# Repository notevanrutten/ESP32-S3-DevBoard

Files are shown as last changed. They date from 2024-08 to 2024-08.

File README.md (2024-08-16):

# ESP32-S3-DevBoard

A custom-built development board using the ESP32-S3 chip

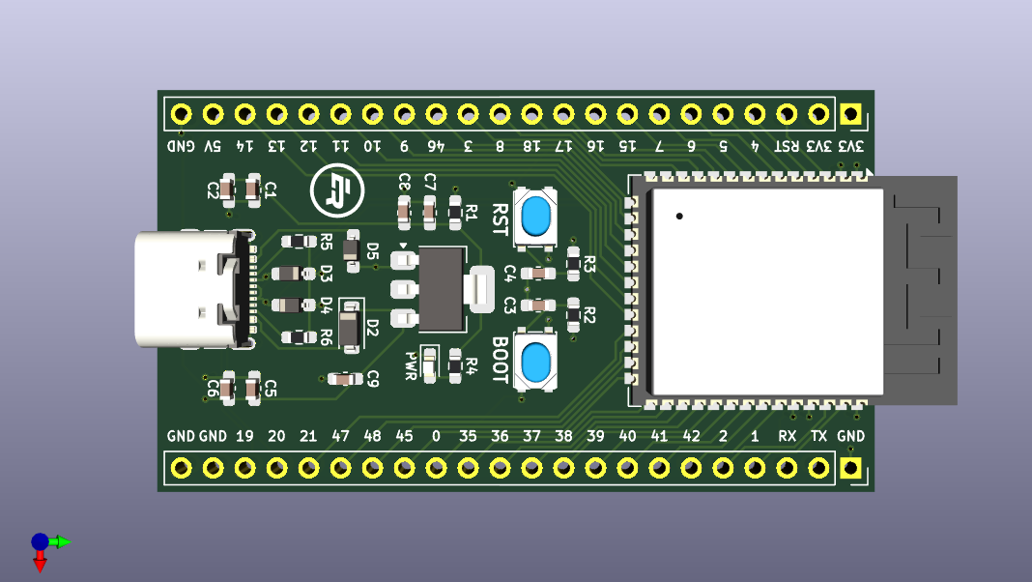
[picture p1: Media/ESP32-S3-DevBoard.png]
ESP32-S3 DevBoard


## PlatformIO Setup

**NOTE:** This process only needs to be performed once for each development board

1. Download the Zadig driver installation program here: https://zadig.akeo.ie
2. Open Zadig, then click `Options -> List All Devices`
3. Select `USB JTAG/serial debug unit (Interface 0)` and change the driver to **USB Serial (CDC)**
4. Click "Upgrade/Downgrade Driver" (please note, this process may take a few minutes)
5. Select `USB JTAG/serial debug unit (Interface 2)` and change the driver to **libusbK**
6. Click "Upgrade/Downgrade Driver" (please note, this process may take a few minutes)
7. In PlatformIO, configure the platformio.ini file as follows:

   ```ini
    [env:esp32-s3-devboard]

    platform = https://github.com/platformio/platform-espressif32.git
    board = esp32-s3-devkitc-1
    framework = arduino

    upload_speed = 2000000
    monitor_speed = 115200

    debug_tool = esp-builtin
    debug_init_break = break setup
    build_type = debug

    ; enables CDC mode (activates USB-to-Serial)
    build_flags = -DARDUINO_USB_CDC_ON_BOOT=1
   ```

## USB Interface Options

### UART Uploading / Monitoring (Standard)

1. Click the PlatformIO icon on the Activity Bar (left)
2. Navigate to `PROJECT TASKS > esp32-s3-devboard > General > Upload and Monitor` (top left)
3. The firmware will be uploaded automatically and the serial output will be displayed in the terminal

### JTAG Debugging + VCOM Monitoring (Advanced)

1. Click the PlatformIO icon on the Activity Bar (left)
2. Navigate to `QUICK ACCESS > Debug > Start Debugging` (bottom left), or press `F5`
3. The firmware will be uploaded automatically and the debug toolbar will appear (top middle)
4. Use the debug toolbar to Pause/Unpause, Restart, or Stop the program (also has code stepping)
5. To view the serial output while code is unpaused, click `PlatformIO: Serial Monitor` on the Status Bar (bottom)

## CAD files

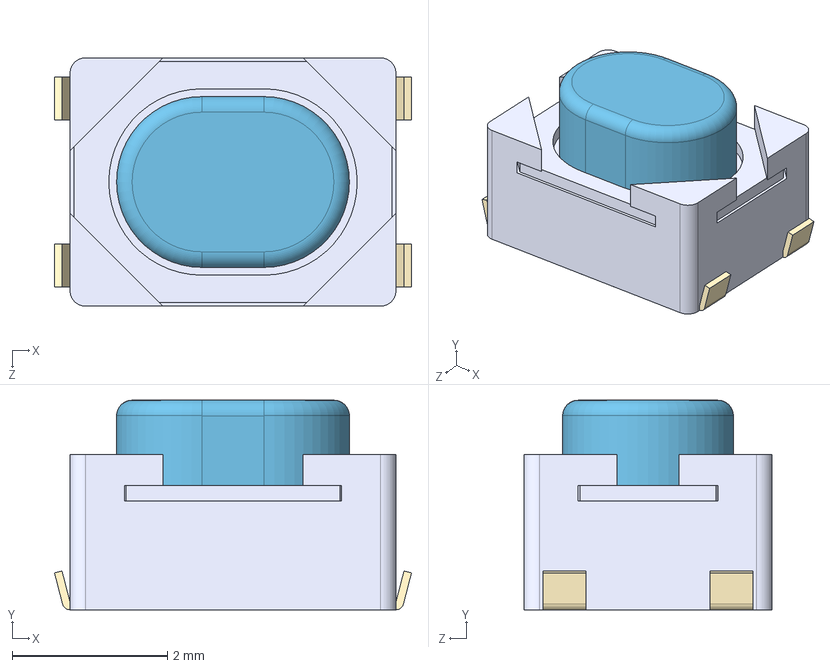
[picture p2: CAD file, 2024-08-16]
Custom/PTS810.STEP
4.60 x 2.70 x 3.20 mm

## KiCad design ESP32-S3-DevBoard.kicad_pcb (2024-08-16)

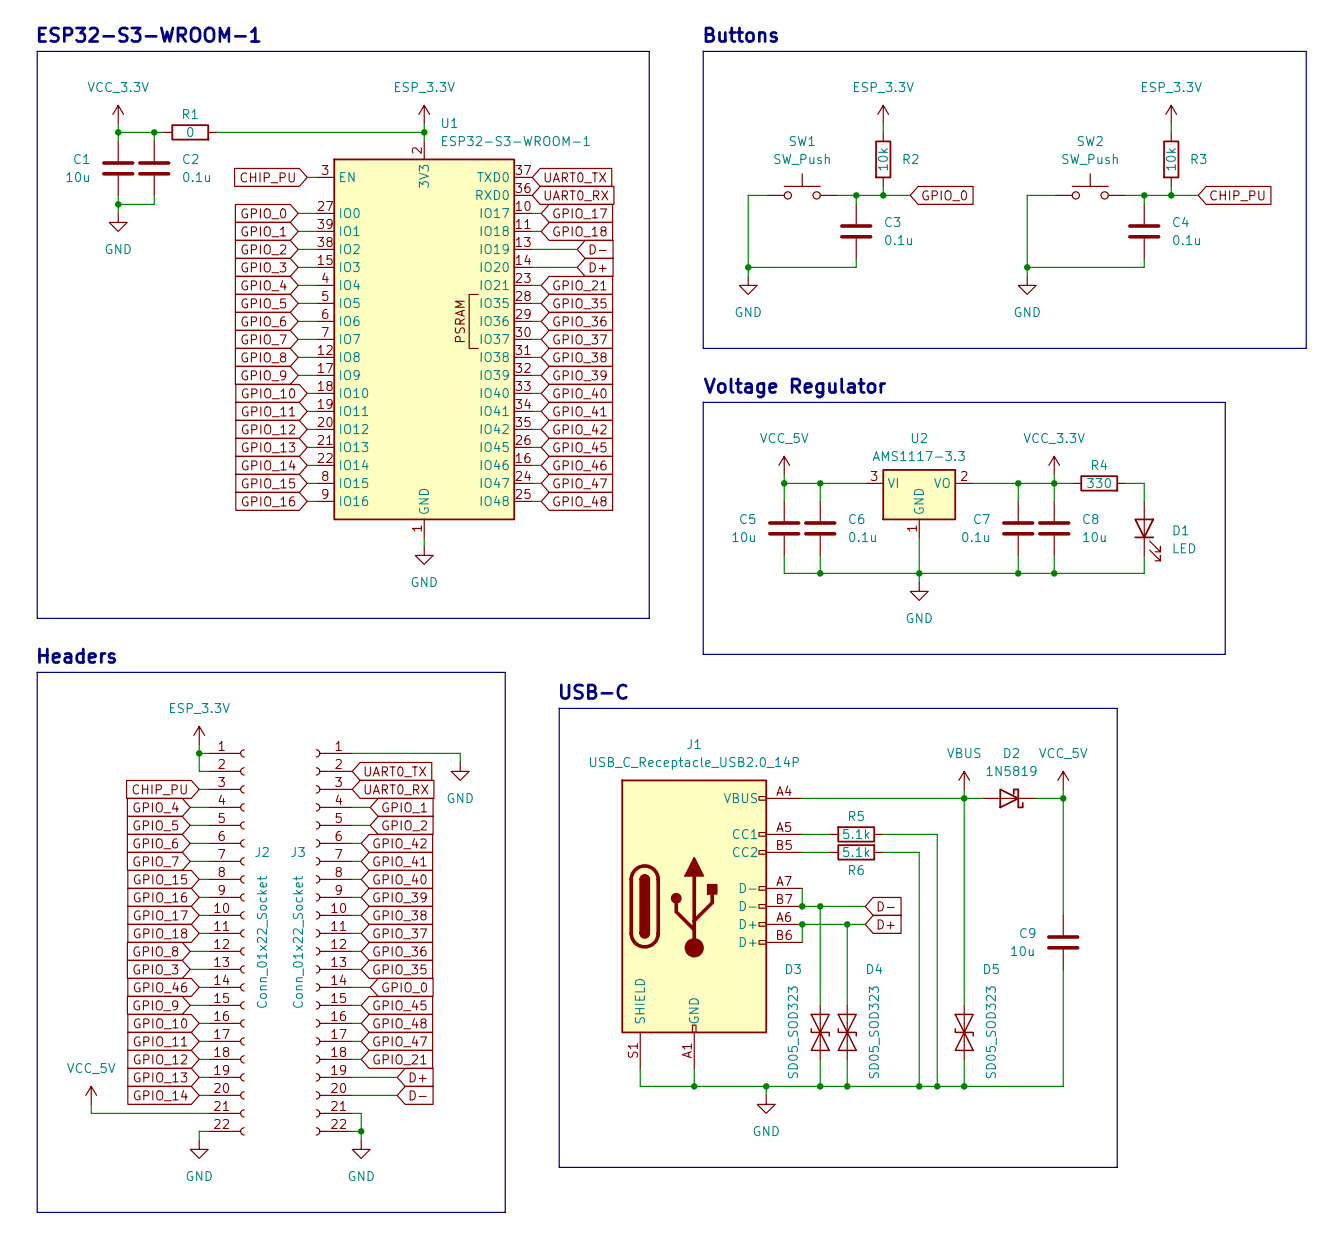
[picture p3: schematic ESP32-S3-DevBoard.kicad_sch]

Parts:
C1, C5, C8, C9: 10u; C_0603_1608Metric_Pad1.08x0.95mm_HandSolder
C2, C3, C4, C6, C7: 0.1u; C_0603_1608Metric_Pad1.08x0.95mm_HandSolder
D1: LED; LED_0603_1608Metric_Pad1.05x0.95mm_HandSolder
D2: 1N5819; D_SOD-123
D3, D4, D5: SD05_SOD323; D_SOD-323_HandSoldering
J1: USB_C_Receptacle_USB2.0_14P; USB_C_Receptacle_GCT_USB4105-xx-A_16P_TopMnt_Horizontal
J2, J3: Conn_01x22_Socket; PinSocket_1x22_P2.54mm_Vertical
R1: 0; R_0603_1608Metric_Pad0.98x0.95mm_HandSolder
R2, R3: 10k; R_0603_1608Metric_Pad0.98x0.95mm_HandSolder
R4: 330; R_0603_1608Metric_Pad0.98x0.95mm_HandSolder
R5, R6: 5.1k; R_0603_1608Metric_Pad0.98x0.95mm_HandSolder
SW1, SW2: SW_Push; SW_SPST_PTS810
U1: ESP32-S3-WROOM-1
U2: AMS1117-3.3; SOT-223-3_TabPin2

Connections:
CHIP_PU: C4.1, J2.3, R3.2, SW2.2, U1.3 (EN)
D+: D4.1 (A1), J1.A6 (D+), J1.B6 (D+), J3.19, U1.14 (IO20)
D-: D3.2 (A2), J1.A7 (D-), J1.B7 (D-), J3.20, U1.13 (IO19)
ESP_3.3V: J2.1, J2.2, R1.2, R2.1, R3.1, U1.2 (3V3)
GND: C1.2, C2.2, C3.2, C4.2, C5.2, C6.2, C7.2, C8.2, C9.2, D1.1 (K), D3.1 (A1), D4.2 (A2), D5.1 (A1), J1.A1 (GND), J1.A12 (GND), J1.B1 (GND), J1.B12 (GND), J1.S1 (SHIELD), J2.22, J3.1, J3.21, J3.22, R5.1, R6.2, SW1.1, SW2.1, U1.1 (GND), U1.40 (GND), U1.41 (GND), U2.1 (GND)
GPIO_0: C3.1, J3.14, R2.2, SW1.2, U1.27 (IO0)
GPIO_1: J3.4, U1.39 (IO1)
GPIO_2: J3.5, U1.38 (IO2)
GPIO_3: J2.13, U1.15 (IO3)
GPIO_4: J2.4, U1.4 (IO4)
GPIO_5: J2.5, U1.5 (IO5)
GPIO_6: J2.6, U1.6 (IO6)
GPIO_7: J2.7, U1.7 (IO7)
GPIO_8: J2.12, U1.12 (IO8)
GPIO_9: J2.15, U1.17 (IO9)
GPIO_10: J2.16, U1.18 (IO10)
GPIO_11: J2.17, U1.19 (IO11)
GPIO_12: J2.18, U1.20 (IO12)
GPIO_13: J2.19, U1.21 (IO13)
GPIO_14: J2.20, U1.22 (IO14)
GPIO_15: J2.8, U1.8 (IO15)
GPIO_16: J2.9, U1.9 (IO16)
GPIO_17: J2.10, U1.10 (IO17)
GPIO_18: J2.11, U1.11 (IO18)
GPIO_21: J3.18, U1.23 (IO21)
GPIO_35: J3.13, U1.28 (IO35)
GPIO_36: J3.12, U1.29 (IO36)
GPIO_37: J3.11, U1.30 (IO37)
GPIO_38: J3.10, U1.31 (IO38)
GPIO_39: J3.9, U1.32 (IO39)
GPIO_40: J3.8, U1.33 (IO40)
GPIO_41: J3.7, U1.34 (IO41)
GPIO_42: J3.6, U1.35 (IO42)
GPIO_45: J3.15, U1.26 (IO45)
GPIO_46: J2.14, U1.16 (IO46)
GPIO_47: J3.17, U1.24 (IO47)
GPIO_48: J3.16, U1.25 (IO48)
unnamed: D1.2 (A), R4.2
unnamed: J1.A5 (CC1), R5.2
unnamed: J1.B5 (CC2), R6.1
UART0_RX: J3.3, U1.36 (RXD0)
UART0_TX: J3.2, U1.37 (TXD0)
VBUS: D2.2 (A), D5.2 (A2), J1.A4 (VBUS), J1.A9 (VBUS), J1.B4 (VBUS), J1.B9 (VBUS)
VCC_3.3V: C1.1, C2.1, C7.1, C8.1, R1.1, R4.1, U2.2 (VO)
VCC_5V: C5.1, C6.1, C9.1, D2.1 (K), J2.21, U2.3 (VI)

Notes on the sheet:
USB-C
Buttons
Headers
ESP32-S3-WROOM-1
Voltage Regulator

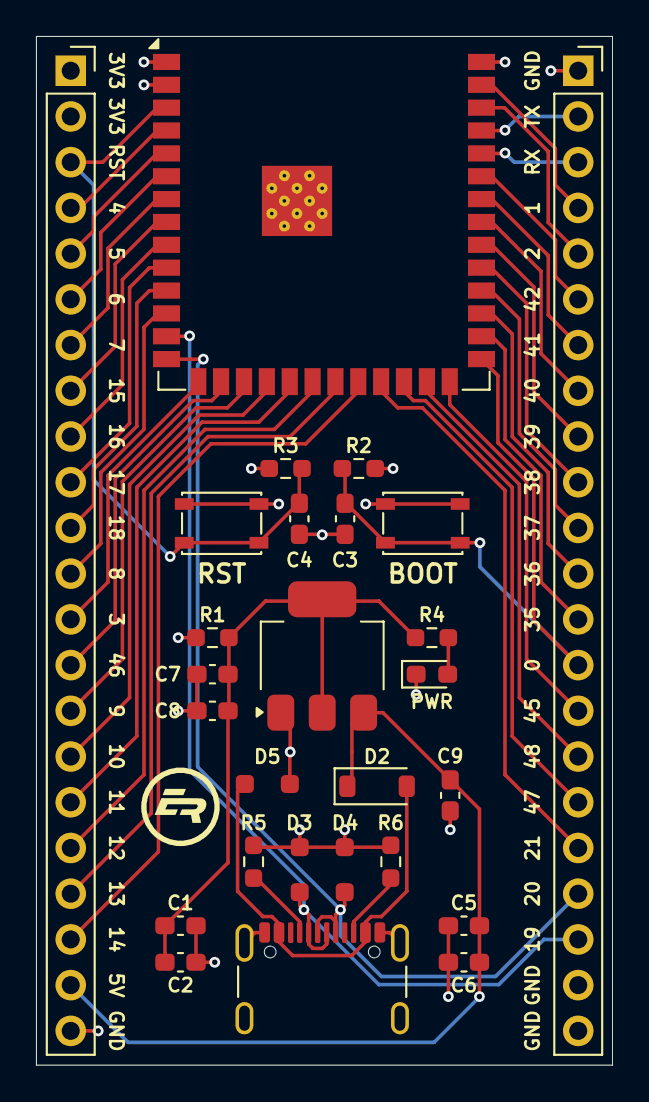
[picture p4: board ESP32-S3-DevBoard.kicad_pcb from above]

Board: 4 copper layers, 32.0 x 57.1 mm, 27 parts (0 on the bottom side), 45 nets.

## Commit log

2024-06-18 Add USB-C interface
    [ESP32-S3-DevBoard.kicad_pcb, ESP32-S3-DevBoard.kicad_sch]
2024-06-20 Change to global tags
    [ESP32-S3-DevBoard.kicad_sch]
2024-06-20 Add USB protection
    [ESP32-S3-DevBoard.kicad_sch]
2024-06-20 Add voltage regulator
    [ESP32-S3-DevBoard.kicad_sch]
2024-06-21 Add buttons and decoupled 3.3V
    [ESP32-S3-DevBoard.kicad_sch]
2024-06-21 Decouple remaining power supplies
    [ESP32-S3-DevBoard.kicad_sch]
2024-06-22 Breakout pins to headers
    [ESP32-S3-DevBoard.kicad_sch]
2024-06-23 Add footprints
    [ESP32-S3-DevBoard.kicad_pcb, ESP32-S3-DevBoard.kicad_sch]
2024-06-23 Route GPIOs and buttons
    [ESP32-S3-DevBoard.kicad_pcb, ESP32-S3-DevBoard.kicad_sch]
2024-06-23 Convert to 4 layer design
    [ESP32-S3-DevBoard.kicad_pcb]
2024-06-24 Update USB-C footprint
    [ESP32-S3-DevBoard.kicad_pcb, ESP32-S3-DevBoard.kicad_sch]
2024-06-24 Finish layout
    [ESP32-S3-DevBoard.kicad_pcb, ESP32-S3-DevBoard.kicad_sch]
2024-06-24 Update PWR/GND planes
    [ESP32-S3-DevBoard.kicad_pcb]
2024-06-24 Add space between USB lines
    [ESP32-S3-DevBoard.kicad_pcb]
2024-06-24 Add impedance matching for USB lines
    [ESP32-S3-DevBoard.kicad_pcb, ESP32-S3-DevBoard.kicad_sch]
2024-06-26 Create gerber files
    [ESP32-S3-DevBoard-B_Cu.gbl, ESP32-S3-DevBoard-B_Mask.gbs, ESP32-S3-DevBoard-B_Paste.gbp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]
2024-06-26 Create BOM file
    [ESP32-S3-DevBoard-B_Cu.gbl, ESP32-S3-DevBoard-B_Mask.gbs, ESP32-S3-DevBoard-B_Paste.gbp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]
2024-06-26 Show BOM file
    [BOM.csv]
2024-06-27 Convert to through-hole vias
    [ESP32-S3-DevBoard-B_Cu.gbl, ESP32-S3-DevBoard-B_Mask.gbs, ESP32-S3-DevBoard-B_Paste.gbp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]
2024-06-29 Fix fabrication files
    [BOM.csv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]
2024-08-15 Add code sample
